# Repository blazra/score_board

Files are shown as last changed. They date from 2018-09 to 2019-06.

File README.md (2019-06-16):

# Score Board

Originally designed for summer camp with a space theme. Boards were used to keep track of points kids got during the camp.

Features:
- ATtiny13A
- 2 rows of 10 LEDs in 1206 package
- 4 corner LEDs in 1206 package
- 1 center APA102-2020 RGB LED
- 3 general purpose buttons + reset
- Powered from JST XH 2 pin connector or on-board CR2032

Schematic: [hardware/score_board.pdf](hardware/score_board.pdf)

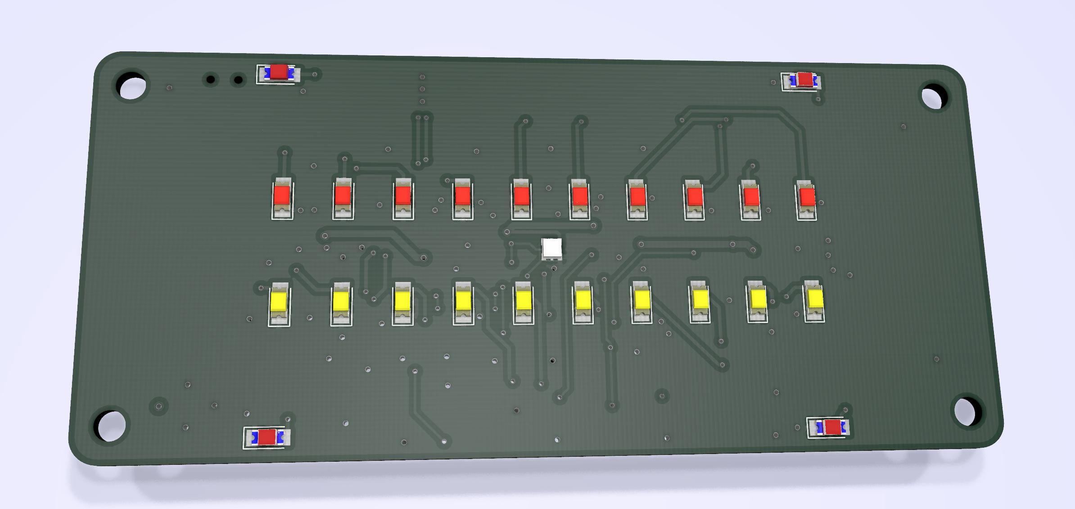
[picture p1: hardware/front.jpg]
frontside render


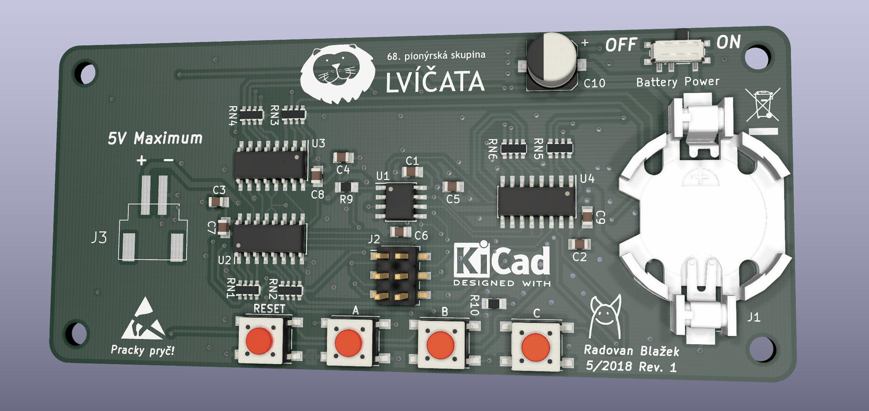
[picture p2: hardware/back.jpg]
backside render


Example use-case:
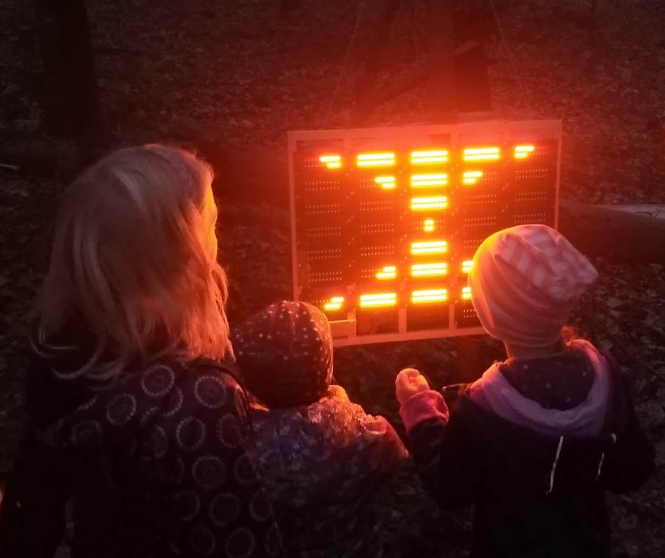
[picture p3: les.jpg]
example use-case


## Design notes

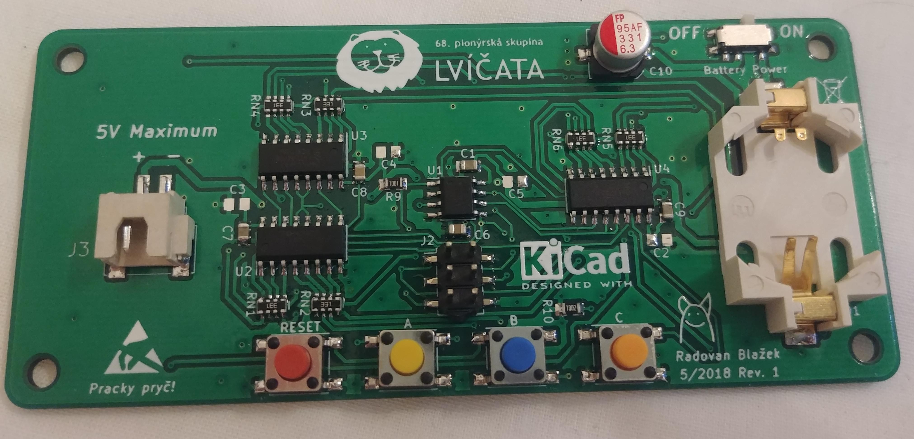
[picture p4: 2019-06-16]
hardware/backside.jpg

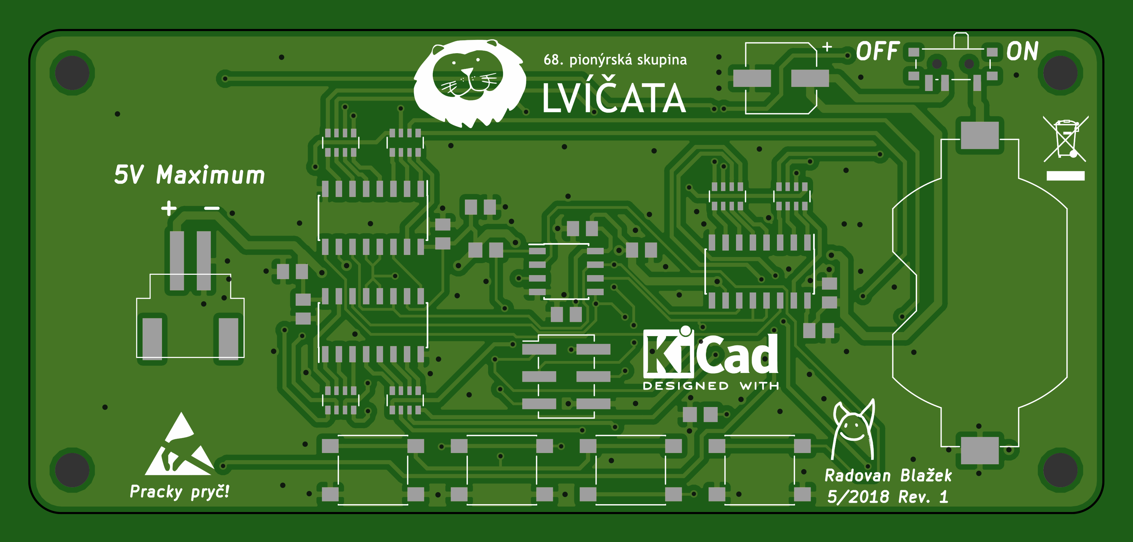
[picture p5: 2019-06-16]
hardware/plot/score_board-Back.png

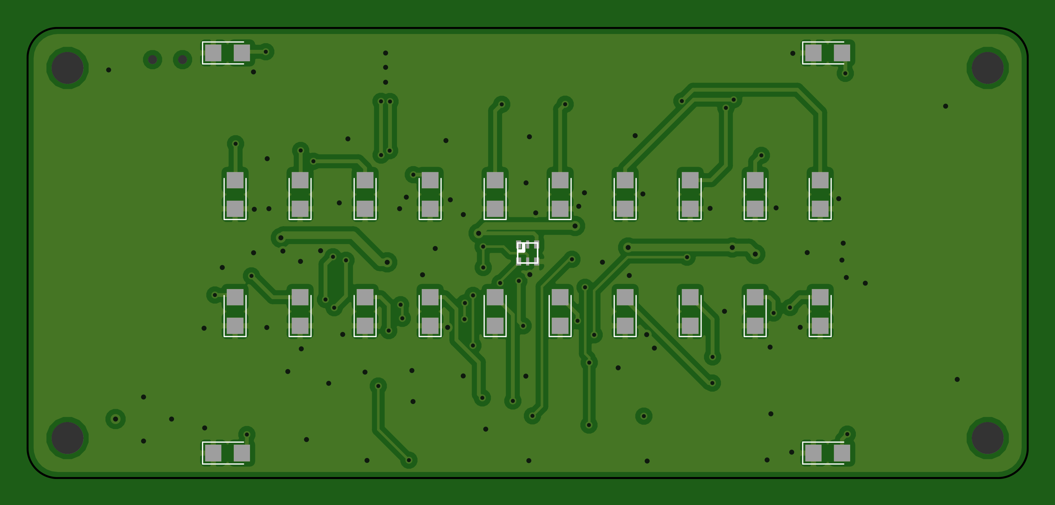
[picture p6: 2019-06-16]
hardware/plot/score_board-Front.png

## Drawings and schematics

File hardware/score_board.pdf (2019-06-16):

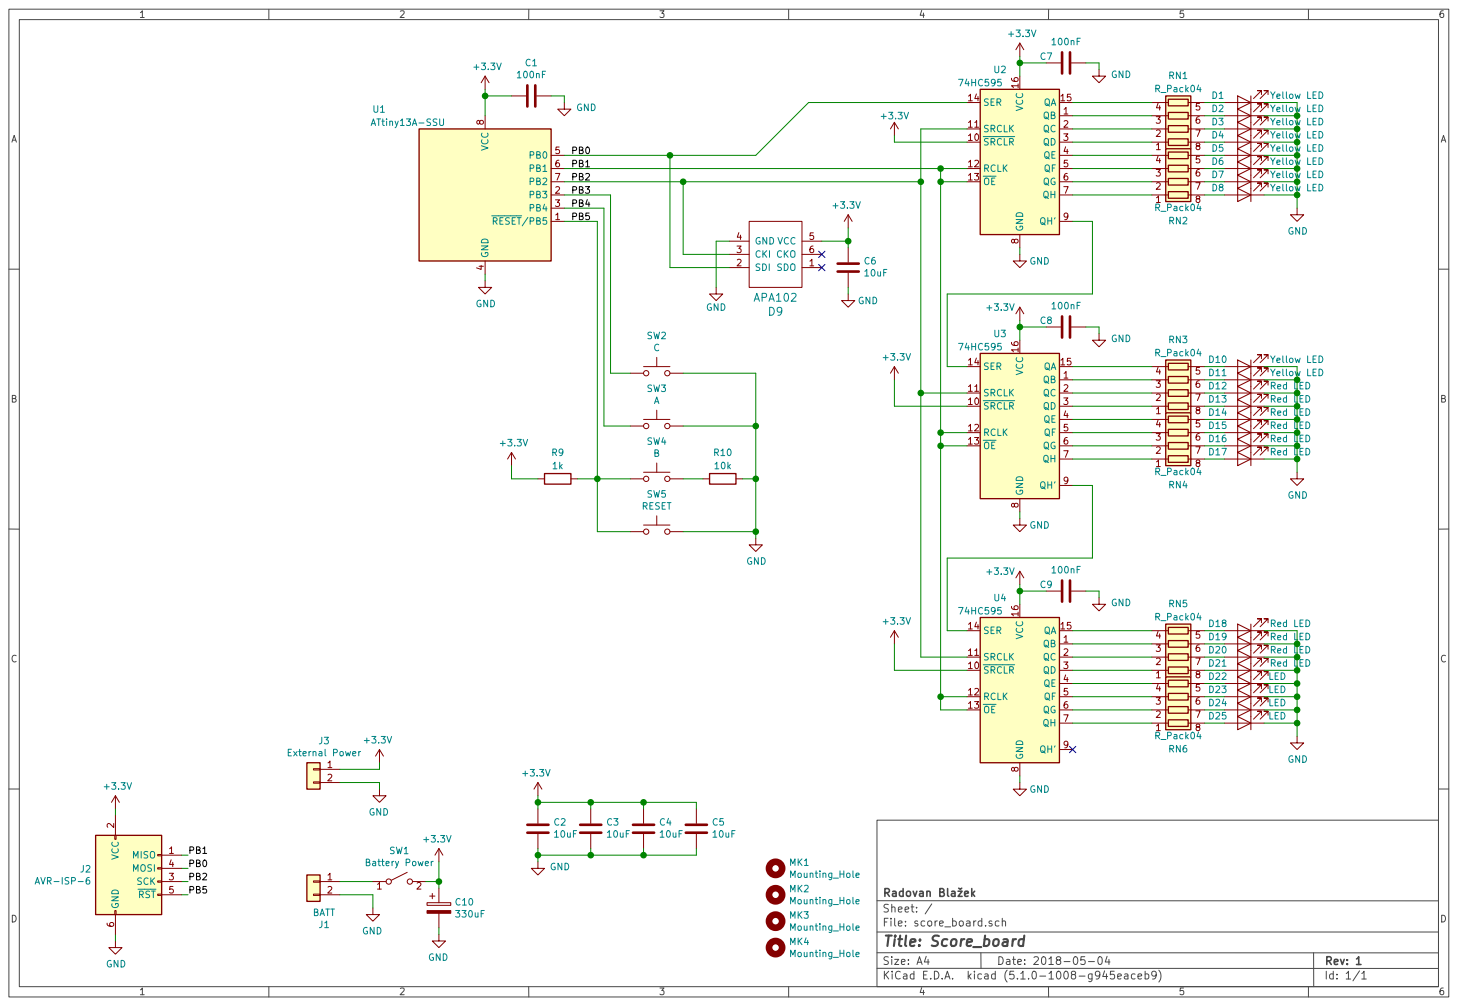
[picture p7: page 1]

D23 | LED
D24 | LED
D25 | LED

File: score_board.sch Sheet: / Radovan Blaek

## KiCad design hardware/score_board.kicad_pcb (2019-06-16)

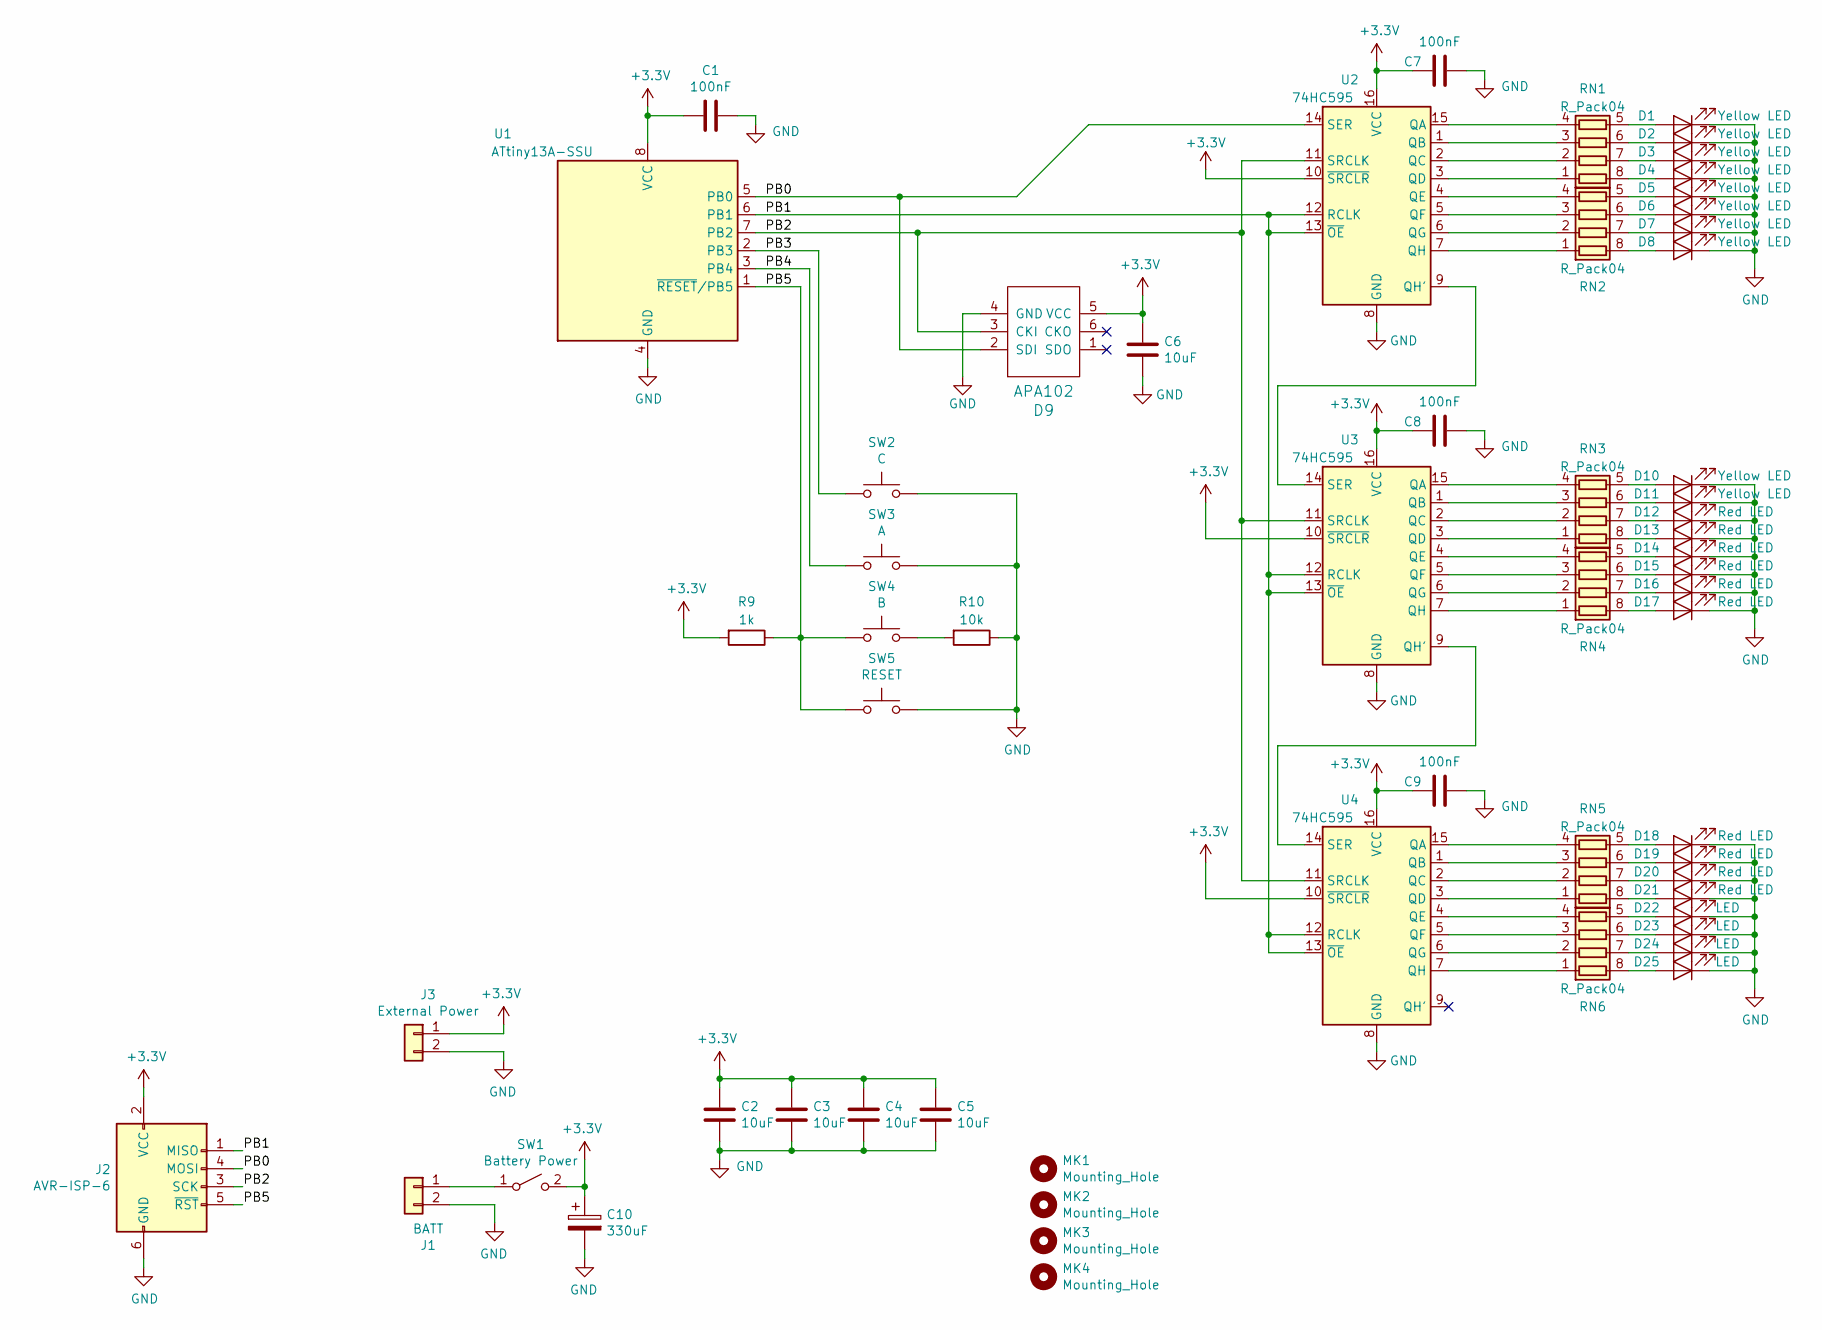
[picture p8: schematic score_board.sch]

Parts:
C1, C7, C8, C9: 100nF; C_0805_2012Metric
C2, C3, C4, C5, C6: 10uF; C_0805_2012Metric
C10: 330uF; CP_Elec_6.3x5.8
D1, D2, D3, D4, D5, D6, D7, D8, D10, D11: Yellow LED; LED_1206_3216Metric_Castellated
D9: APA102; APA102-2020
D12, D13, D14, D15, D16, D17, D18, D19, D20, D21: Red LED; LED_1206_3216Metric_Castellated
D22, D23, D24, D25: LED; LED_1206_3216Metric_Castellated
J1: BATT; BatteryHolder_Keystone_1058_1x2032
J2: AVR-ISP-6; PinHeader_2x03_P2.54mm_Vertical_SMD
J3: External Power; JST XH SMD 2P
MK1, MK2, MK3, MK4: Mounting_Hole; MountingHole_3.2mm_M3
R9: 1k; R_0805_2012Metric_Pad1.29x1.40mm_HandSolder
R10: 10k; R_0805_2012Metric_Pad1.29x1.40mm_HandSolder
RN1, RN2, RN3, RN4, RN5, RN6: R_Pack04; R_Array_Convex_4x0603
SW1: Battery Power; SW_SPDT_PCM12
SW2: C; SW_SPST_PTS645
SW3: A; SW_SPST_PTS645
SW4: B; SW_SPST_PTS645
SW5: RESET; SW_SPST_PTS645
U1: ATtiny13A-SSU; SOIC-8_3.9x4.9mm_P1.27mm
U2, U3, U4: 74HC595; SOIC-16_3.9x9.9mm_P1.27mm

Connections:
+3V3: C1.2, C2.2, C3.2, C4.2, C5.2, C6.2, C7.2, C8.2, C9.2, C10.1, D9.5 (VCC), J2.2 (VCC), J3.1, R9.2, SW1.2 (B), U1.8 (VCC), U2.10 (~SRCLR), U2.16 (VCC), U3.10 (~SRCLR), U3.16 (VCC), U4.10 (~SRCLR), U4.16 (VCC)
/PB0: D9.2 (SDI), J2.4 (MOSI), U1.5 (PB0), U2.14 (SER)
/PB1: J2.1 (MISO), U1.6 (PB1), U2.12 (RCLK), U2.13 (~OE), U3.12 (RCLK), U3.13 (~OE), U4.12 (RCLK), U4.13 (~OE)
/PB2: D9.3 (CKI), J2.3 (SCK), U1.7 (PB2), U2.11 (SRCLK), U3.11 (SRCLK), U4.11 (SRCLK)
/PB3: SW2.1, U1.2 (PB3)
/PB4: SW3.1, U1.3 (PB4)
/PB5: J2.5 (~RST), R9.1, SW4.1, SW5.1, U1.1 (~RESET~/PB5)
GND: C1.1, C2.1, C3.1, C4.1, C5.1, C6.1, C7.1, C8.1, C9.1, C10.2, D1.1 (K), D2.1 (K), D3.1 (K), D4.1 (K), D5.1 (K), D6.1 (K), D7.1 (K), D8.1 (K), D9.4 (GND), D10.1 (K), D11.1 (K), D12.1 (K), D13.1 (K), D14.1 (K), D15.1 (K), D16.1 (K), D17.1 (K), D18.1 (K), D19.1 (K), D20.1 (K), D21.1 (K), D22.1 (K), D23.1 (K), D24.1 (K), D25.1 (K), J1.2, J2.6 (GND), J3.2, R10.1, SW2.2, SW3.2, SW5.2, U1.4 (GND), U2.8 (GND), U3.8 (GND), U4.8 (GND)
unnamed: D1.2 (A), RN1.5 (R4.2)
unnamed: D2.2 (A), RN1.6 (R3.2)
unnamed: D3.2 (A), RN1.7 (R2.2)
unnamed: D4.2 (A), RN1.8 (R1.2)
unnamed: D5.2 (A), RN2.5 (R4.2)
unnamed: D6.2 (A), RN2.6 (R3.2)
unnamed: D7.2 (A), RN2.7 (R2.2)
unnamed: D8.2 (A), RN2.8 (R1.2)
unnamed: D10.2 (A), RN3.5 (R4.2)
unnamed: D11.2 (A), RN3.6 (R3.2)
unnamed: D12.2 (A), RN3.7 (R2.2)
unnamed: D13.2 (A), RN3.8 (R1.2)
unnamed: D14.2 (A), RN4.5 (R4.2)
unnamed: D15.2 (A), RN4.6 (R3.2)
unnamed: D16.2 (A), RN4.7 (R2.2)
unnamed: D17.2 (A), RN4.8 (R1.2)
unnamed: D18.2 (A), RN5.5 (R4.2)
unnamed: D19.2 (A), RN5.6 (R3.2)
unnamed: D20.2 (A), RN5.7 (R2.2)
unnamed: D21.2 (A), RN5.8 (R1.2)
unnamed: D22.2 (A), RN6.5 (R4.2)
unnamed: D23.2 (A), RN6.6 (R3.2)
unnamed: D24.2 (A), RN6.7 (R2.2)
unnamed: D25.2 (A), RN6.8 (R1.2)
unnamed: J1.1, SW1.1 (A)
unnamed: R10.2, SW4.2
unnamed: RN1.1 (R1.1), U2.3 (QD)
unnamed: RN1.2 (R2.1), U2.2 (QC)
unnamed: RN1.3 (R3.1), U2.1 (QB)
unnamed: RN1.4 (R4.1), U2.15 (QA)
unnamed: RN2.1 (R1.1), U2.7 (QH)
unnamed: RN2.2 (R2.1), U2.6 (QG)
unnamed: RN2.3 (R3.1), U2.5 (QF)
unnamed: RN2.4 (R4.1), U2.4 (QE)
unnamed: RN3.1 (R1.1), U3.3 (QD)
unnamed: RN3.2 (R2.1), U3.2 (QC)
unnamed: RN3.3 (R3.1), U3.1 (QB)
unnamed: RN3.4 (R4.1), U3.15 (QA)
unnamed: RN4.1 (R1.1), U3.7 (QH)
unnamed: RN4.2 (R2.1), U3.6 (QG)
unnamed: RN4.3 (R3.1), U3.5 (QF)
unnamed: RN4.4 (R4.1), U3.4 (QE)
unnamed: RN5.1 (R1.1), U4.3 (QD)
unnamed: RN5.2 (R2.1), U4.2 (QC)
unnamed: RN5.3 (R3.1), U4.1 (QB)
unnamed: RN5.4 (R4.1), U4.15 (QA)
unnamed: RN6.1 (R1.1), U4.7 (QH)
unnamed: RN6.2 (R2.1), U4.6 (QG)
unnamed: RN6.3 (R3.1), U4.5 (QF)
unnamed: RN6.4 (R4.1), U4.4 (QE)
unnamed: U2.9 (QH'), U3.14 (SER)
unnamed: U3.9 (QH'), U4.14 (SER)

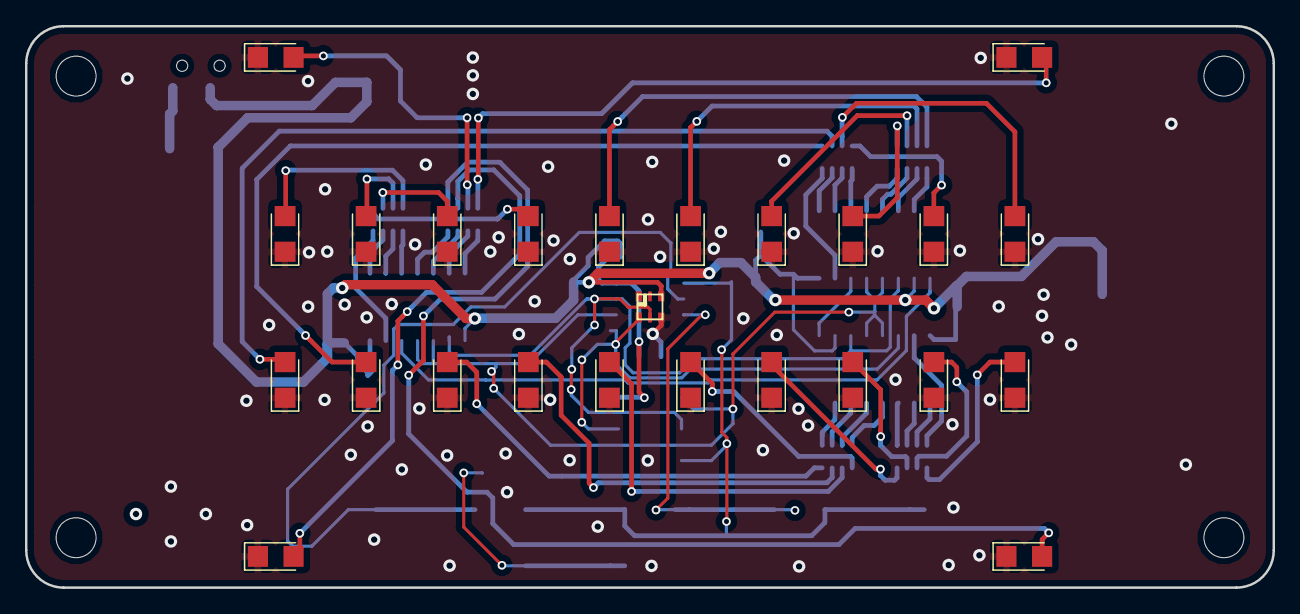
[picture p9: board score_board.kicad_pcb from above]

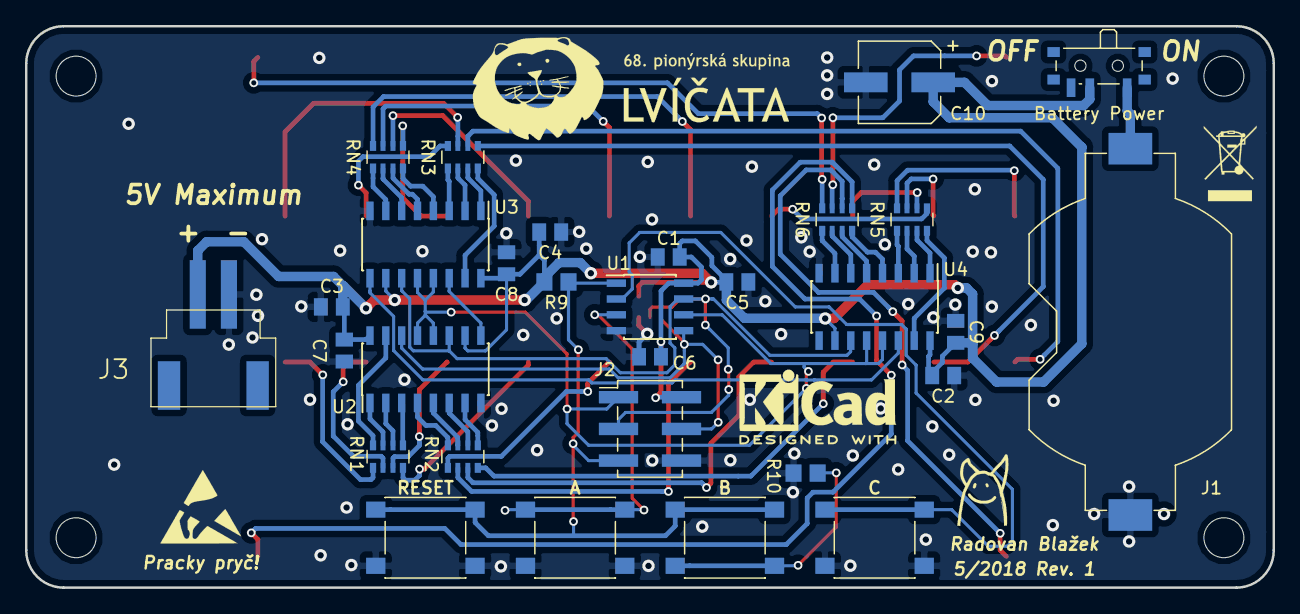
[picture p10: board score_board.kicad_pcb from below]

Board: 2 copper layers, 100.0 x 45.0 mm, 59 parts (30 on the bottom side), 60 nets.

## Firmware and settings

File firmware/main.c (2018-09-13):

#include <avr/io.h>
#include <avr/sleep.h>
#include <avr/interrupt.h>
#include <avr/wdt.h>

#define SCLK 2
#define MOSI 0
#define OE 1   // Active low
#define SW_C 3
#define SW_A 4

uint8_t cursor;
uint8_t id;
uint8_t state;
uint32_t leds;
uint32_t idum;


void delay(uint8_t delay)
{
    uint8_t i;
    for (uint8_t j = 0; j < delay; ++j)
    {
        i = 0;
        while(--i)
            __asm__("");
    }
}

void WDT_off(void)
{
    cli();
    wdt_reset();
    /* Clear WDRF in MCUSR */
    MCUSR &= ~(1<<WDRF);
    /* Write logical one to WDCE and WDE */
    /* Keep old prescaler setting to prevent unintentional time-out */
    WDTCR |= (1<<WDCE) | (1<<WDE);
    /* Turn off WDT */
    WDTCR = 0x00;
    sei();
}

void EEPROM_write(uint8_t ucAddress, uint8_t ucData)
{
    /* Wait for completion of previous write */
    while(EECR & (1<<EEPE))
    ;
    /* Set Programming mode */
    EECR = (0<<EEPM1)|(0>>EEPM0);
    /* Set up address and data registers */
    EEARL = ucAddress;
    EEDR = ucData;
    /* Write logical one to EEMPE */
    EECR |= (1<<EEMPE);
    /* Start eeprom write by setting EEPE */
    EECR |= (1<<EEPE);
}

unsigned char EEPROM_read(uint8_t ucAddress)
{
    /* Wait for completion of previous write */
    while(EECR & (1<<EEPE))
    ;
    /* Set up address register */
    EEARL = ucAddress;
    /* Start eeprom read by writing EERE */
    EECR |= (1<<EERE);
    /* Return data from data register */
    return EEDR;
}

void EEPROM_write_32b(uint8_t address ,uint32_t data)
{
    EEPROM_write(address, data);
    EEPROM_write(address+1, data>>8);
    EEPROM_write(address+2, data>>16);
    EEPROM_write(address+3, data>>24);
}

uint32_t EEPROM_read_32b(uint8_t address)
{
    uint32_t data = 0;
    data = EEPROM_read(address);
    data |= (uint32_t)EEPROM_read(address+1)<<8;
    data |= (uint32_t)EEPROM_read(address+2)<<16;
    data |= (uint32_t)EEPROM_read(address+3)<<24;
    return data;
}

void spi_write_byte(uint8_t data)
{
    for (uint8_t i = 0; i < 8; i++)
    {
        // Set SCLK low
        PORTB &= ~(1<<SCLK);
        // MSB first
        if(data & (0x80>>i))
            PORTB |= (1<<MOSI);     // Set MOSI high
        else
            PORTB &= ~(1<<MOSI);    // Set MOSI low
        // Set SCLK high
        PORTB |= (1<<SCLK);       
    }
}

void leds_update(uint32_t data)
{
    // Disable output
    PORTB |=  (1<<OE);

    spi_write_byte(255);
    spi_write_byte((uint8_t)(data >> 16));
    spi_write_byte((uint8_t)(data >> 8));
    spi_write_byte((uint8_t)(data));

    // Load data from shift regs to storage regs and enable output
    PORTB &= ~(1<<OE);
    PORTB |=  (1<<OE);
    PORTB &= ~(1<<OE);
}

// void show_score(uint8_t score)
// {
//     uint8_t units = score % 10;
//     uint8_t tens = score / 10;
//     if((units == 0) && (tens != 0))
//     {
//         tens--;
//         units = 10;
//     }
//     leds_update( (0xfffffc00 << (10-units)) | ((0xffff << (10-tens)) & 0x03ff) );
// }

void leds_blink(uint32_t data, uint8_t duration, uint8_t blank, uint8_t num_of_blinks)
{
    for (uint8_t i = 0; i < num_of_blinks; i++)
    {
        leds_update(data);
        delay(duration);
        leds_update(0ul);
        delay(blank);
    }
}

uint32_t rand()
{
    idum = 1664525L*idum + 1013904223L;
    return idum;
}

int main(void)
{
    WDT_off();

    // Set pins to output mode
    DDRB = (1<<SCLK) | (1<<MOSI) | (1<<OE);
    // Enable pull-ups on inputs and set OE high, because it's active low
    PORTB = (1<<OE) | (1<<SW_A) | (1<<SW_C);


    leds_update(0x00000000);
    delay(255);

    spi_write_byte(0x00);
    spi_write_byte(0x00);
    spi_write_byte(0x00);
    spi_write_byte(0x00);

    spi_write_byte(0xff);
    spi_write_byte(0x00);
    spi_write_byte(0x00);
    spi_write_byte(0x00);

    spi_write_byte(0xff);
    spi_write_byte(0xff);
    spi_write_byte(0xff);
    spi_write_byte(0xff);

    leds_blink(0x000003ff, 100, 100, 1);
    leds_blink(0x00fffc00, 100, 100, 1);

    for (uint8_t i = 0; i < 10; ++i)
    {
        leds_update(rand());
        delay(100);
    }


    id = EEPROM_read(0);
    idum = id;
    leds = EEPROM_read_32b(3);

    //if(score > 110)
    //    score = 0;
    //EEPROM_write(1, score);
    
    

    
    
    state = 0x00;

    while(1)
    {
        //leds_update(leds | (0xfffffffful>>(32-score)));
        // delay(100);
        // if(leds & (1<<10))
        //     state = 0;
        // if(leds & (1ul<<19))
        //     state = 1;
        // if(state)
        //     leds = leds >> 1;
        // else
        //     leds = leds << 1;


        //leds_update( (0xffff << (10-(score % 10)))  );
        //show_score(score);

        leds_update(leds);

        if(~PINB & (1<<PINB3))
        {
            if(cursor >= 19)
                cursor = 0;
            else
                cursor++;
            leds_update(leds);
            EEPROM_write_32b(3, leds);
            delay(10);
            while(~PINB & (1<<SW_C))
                ;
        }
        else if(~PINB & (1<<SW_A))
        {
            leds ^= 1ul<<cursor;
            leds_update(leds);
            EEPROM_write_32b(3, leds);
            delay(10);
            while(~PINB & (1<<SW_A))
                ;
        }
        delay(100);
    }
}

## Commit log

2018-09-13 add RGB led compatibility
2018-09-13 change behaviour, so you can set any LED to be on or off
2019-06-16 Add hardware and new dir structure
    [score_board-B.Cu.gbr, score_board-B.Mask.gbr, score_board-B.Paste.gbr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]
2019-06-16 Fix some kicad libraries issues
    [score_board.kicad_pcb, score_board.sch]
2019-06-16 Add schematic in pdf
2019-06-16 Add photo of example use-case
